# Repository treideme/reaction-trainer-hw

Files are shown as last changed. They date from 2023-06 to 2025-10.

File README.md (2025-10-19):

# Next-Generation Reaction Trainer

This repository contains the hardware design, such as PCB files and
mechanical CAD files for the IoT contest. 

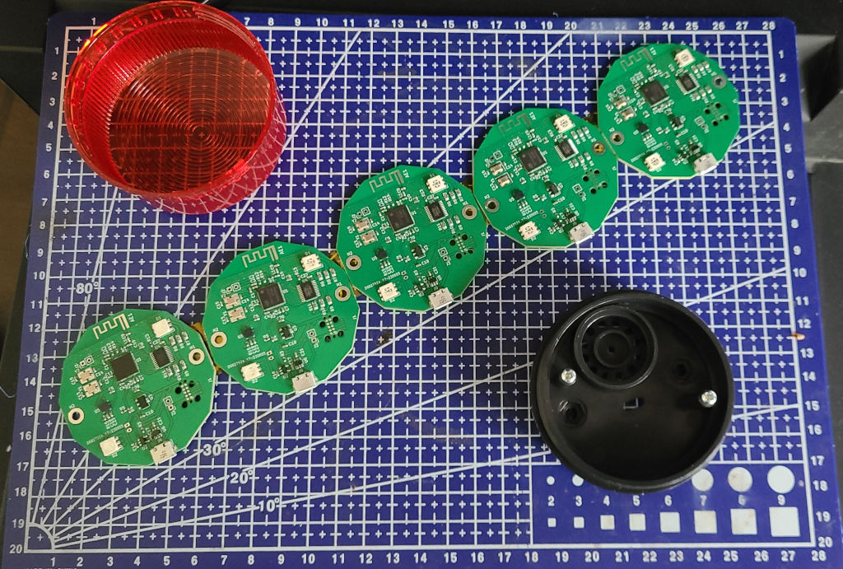
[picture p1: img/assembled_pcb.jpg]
Assembled PCB

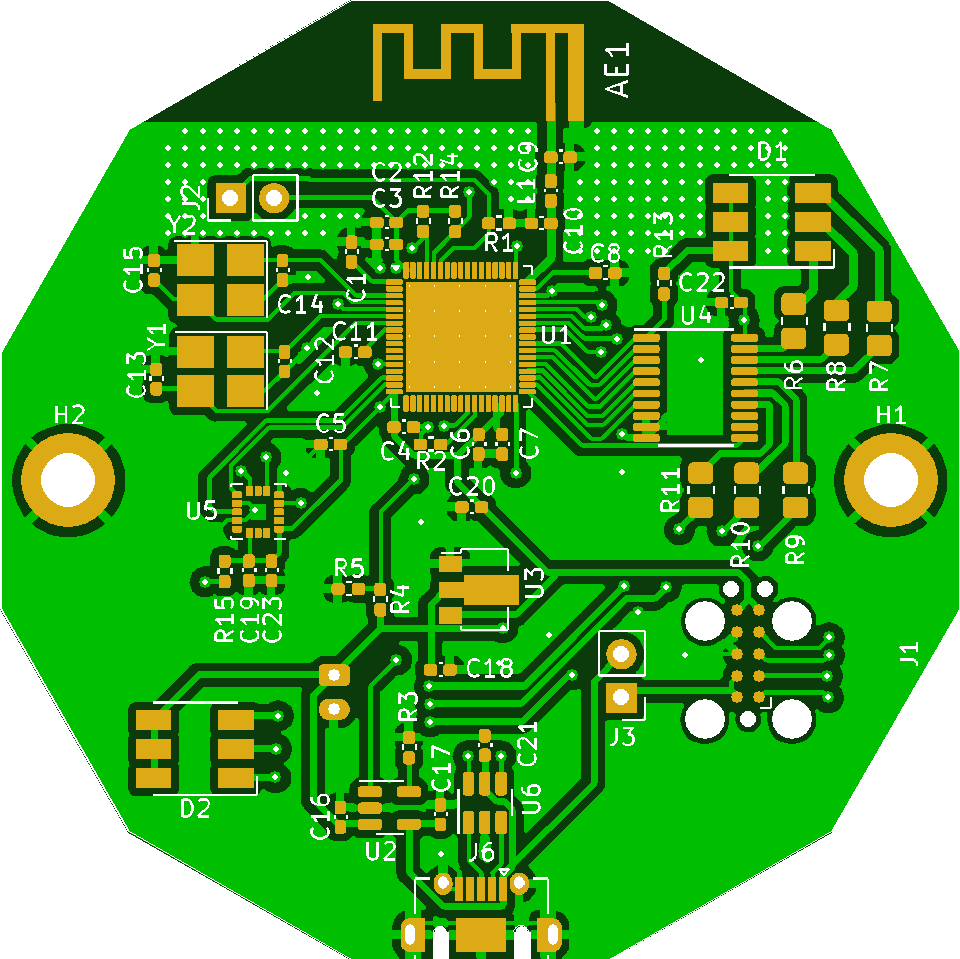
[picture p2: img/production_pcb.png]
Production PCB

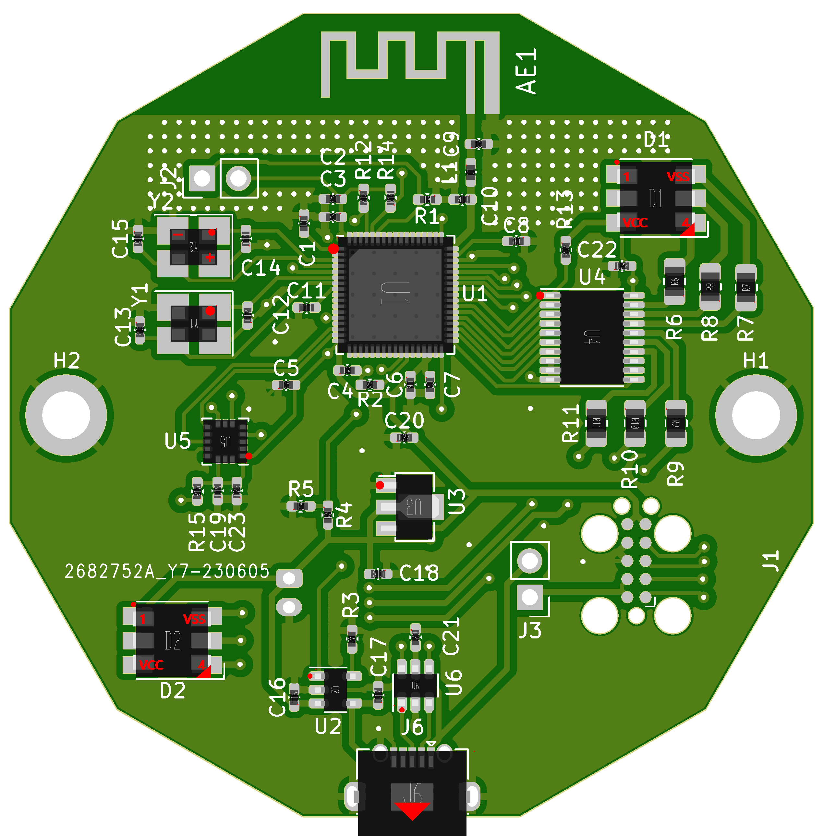
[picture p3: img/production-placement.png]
Production Placement


Please see my [blog post](https://reidemeister.com/blog/2023.06.06)
for a detailed run-down of the design.

## Requirements 
 * Kicad 6+
 * my fork of [WCH Kicad LBR](https://github.com/treideme/wch-kicad-lbr) to get CH32V208W library parts
   * Big shout out to [sad-electronics](https://github.com/sad-electronics) for laying the ground work

See [my blog post](https://www.reidemeister.com/?p=624) for more information and build updates.

 * [Firmware Sources and Overview](https://github.com/treideme/reaction-trainer)
 * [Android Application Sources](https://github.com/treideme/reaction-trainer-app)

## [Bringup](BRINGUP.md)

----
(C) 2023 Thomas Reidemeister, released under [CERN-OHL-P](LICENSE).

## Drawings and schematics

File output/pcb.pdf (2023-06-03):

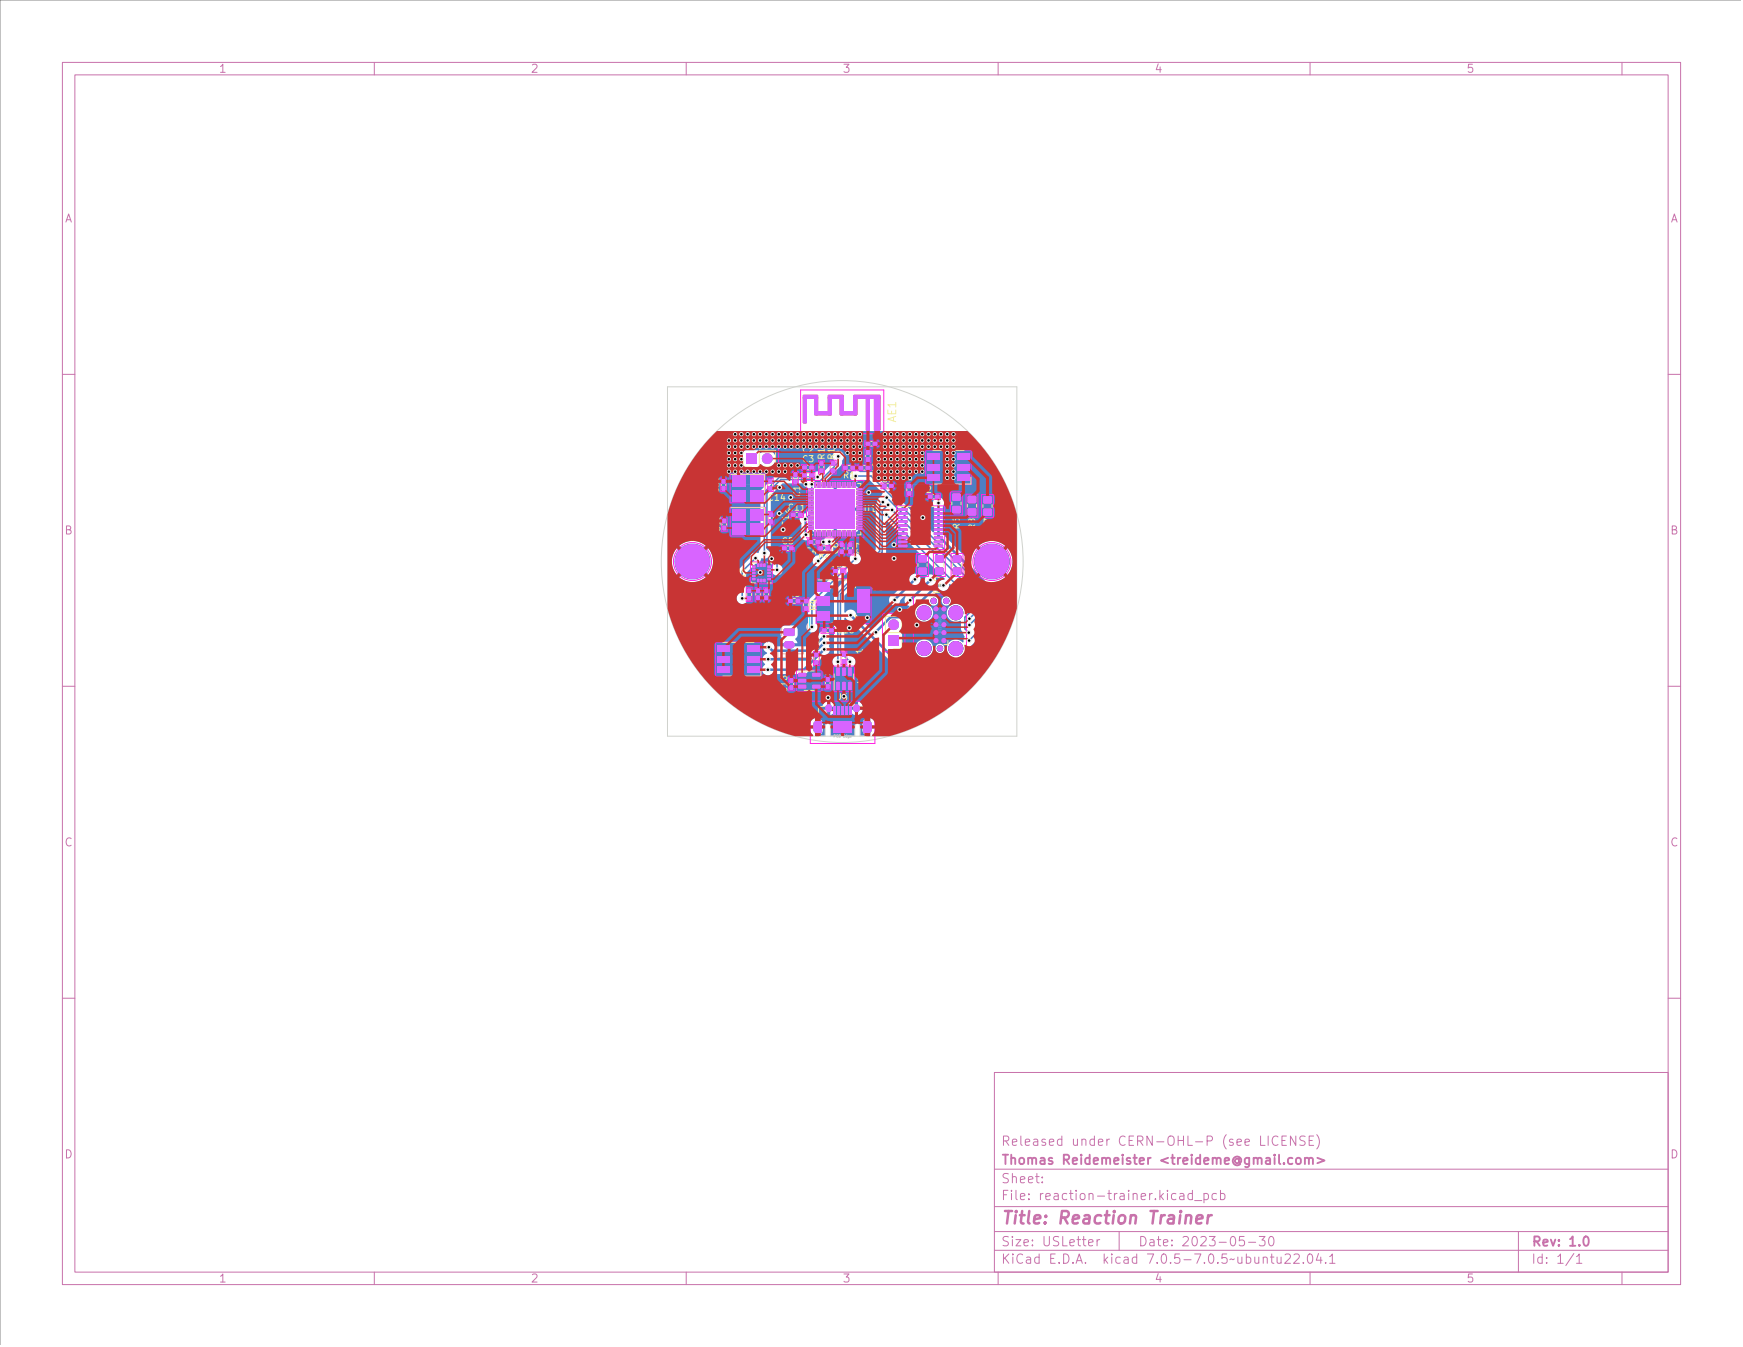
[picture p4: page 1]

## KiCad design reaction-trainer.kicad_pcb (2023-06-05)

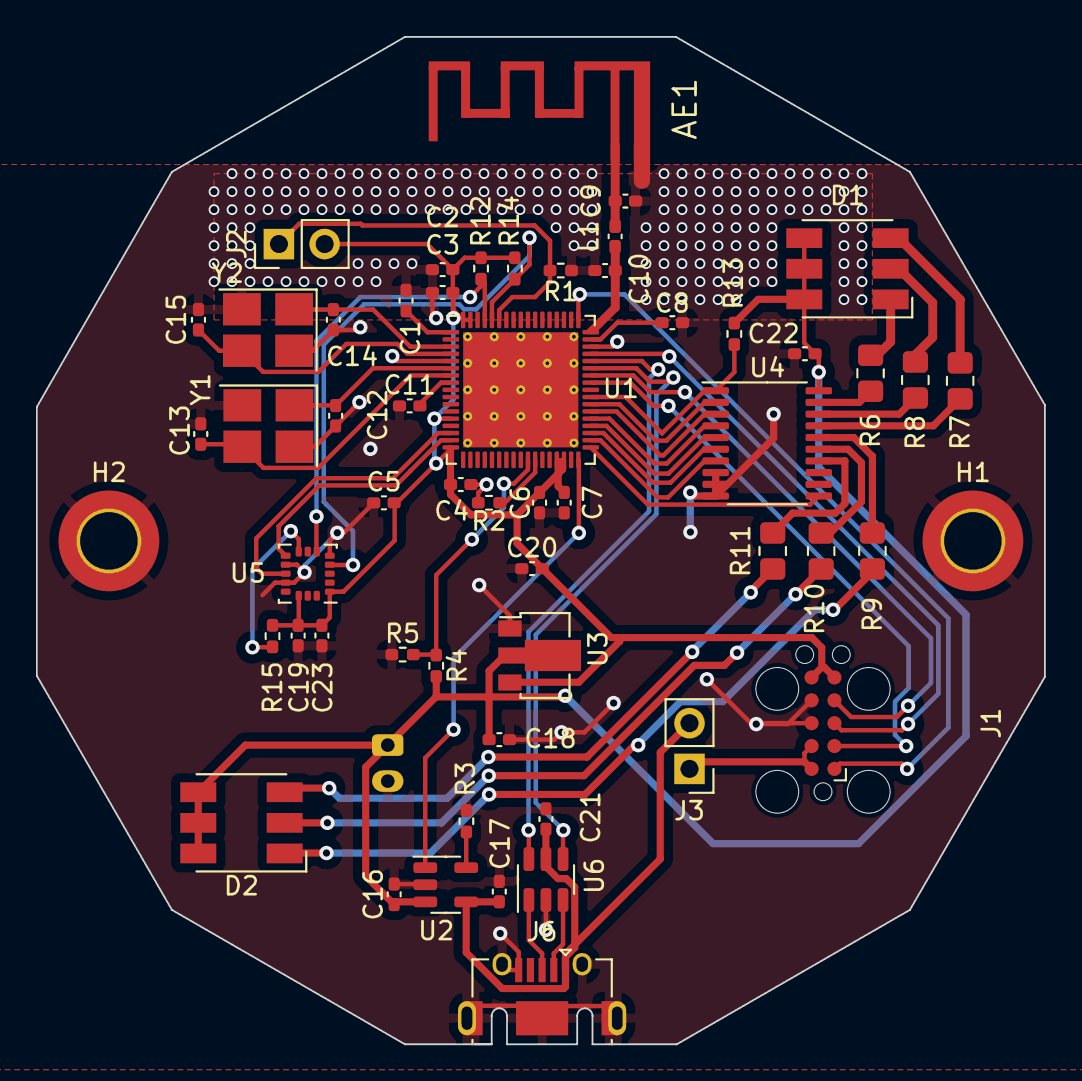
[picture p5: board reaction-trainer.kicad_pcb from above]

Board: 2 copper layers, 56.0 x 56.0 mm, 57 parts (1 on the bottom side), 52 nets.

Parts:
AE1: Antenna_Shield; ANT-F-1-2.4G-1.6MM-FR4-WCH
C1, C2, C3, C4, C5, C6, C7, C11, C21, C22, C23: 0.1uF 20%; C_0402_1005Metric_Pad0.74x0.62mm_HandSolder
C8, C16, C17, C18, C19, C20: 10uF 20%; C_0402_1005Metric_Pad0.74x0.62mm_HandSolder
C9: 1.5pF 5%; C_0402_1005Metric_Pad0.74x0.62mm_HandSolder
C10: 1pF 5%; C_0402_1005Metric_Pad0.74x0.62mm_HandSolder
C12, C13: 12pF 5%; C_0402_1005Metric_Pad0.74x0.62mm_HandSolder
C14, C15: 15pF 5%; C_0402_1005Metric_Pad0.74x0.62mm_HandSolder
D1, D2: C784541; LED_RGB_5050-6
H1, H2: MountingHole_Pad; MountingHole_3.2mm_M3_DIN965_Pad_TopBottom
J1: TC2050; Tag-Connect_TC2050-IDC-FP_2x05_P1.27mm_Vertical
J2, J3: DNP; PinHeader_1x02_P2.54mm_Vertical
J5: JST_PH_B2B; JST_PH_B2B-PH-K_1x02_P2.00mm_Vertical
J6: 47590-0001; USB_Micro-AB_Molex_47590-0001
L1: 1.8nH; L_0402_1005Metric_Pad0.77x0.64mm_HandSolder
R1, R2, R3, R12, R13, R14, R15: 10K 5%; R_0402_1005Metric_Pad0.72x0.64mm_HandSolder
R4: 510K 1%; R_0402_1005Metric_Pad0.72x0.64mm_HandSolder
R5: 1M 1%; R_0402_1005Metric_Pad0.72x0.64mm_HandSolder
R6, R7, R9, R11: 15 5% 125mW; R_0805_2012Metric_Pad1.20x1.40mm_HandSolder
R8, R10: 30 5% 125mW; R_0805_2012Metric_Pad1.20x1.40mm_HandSolder
U1: CH32V208WBU6; QFN-68-1EP_8x8mm_P0.4mm_EP6.4x6.4mm_ThermalVias
U2: MCP73831-2-OT; SOT-23-5
U3: HT7533-1; SOT-89-3
U4: 74HC573PW,118; TSSOP-20_4.4x6.5mm_P0.65mm
U5: LIS3DHTR; LGA-16_3x3mm_P0.5mm_LayoutBorder3x5y
U6: USBLC6-2SC6; SOT-23-6
Y1: 32MHz; Crystal_SMD_3225-4Pin_3.2x2.5mm_HandSoldering
Y2: 32768Hz; Crystal_SMD_3225-4Pin_3.2x2.5mm_HandSoldering

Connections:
+3V3: C2.1, C3.1, C4.1, C5.2, C6.1, C7.1, C19.2, C20.2, C23.2, J1.5, J1.6, J2.2, R12.1, R14.2, R15.2, U1.13 (VDDA), U1.17 (VIO_4), U1.31 (VIO_1), U1.32 (VDD_1), U1.67 (VIO_3), U1.68 (VDD_3), U3.3 (VOUT), U5.1 (VDD_IO), U5.14 (VDD)
+5V: C17.1, C21.2, J3.2, J6.1 (VBUS), U2.4 (VDD), U6.5 (VBUS)
+BATT: C16.1, C18.2, C22.2, D1.4 (BA), D1.5 (GA), D1.6 (RA), D2.4 (BA), D2.5 (GA), D2.6 (RA), J5.1, R4.2, R13.1, U2.3 (VBAT), U3.2 (VIN), U4.20 (VCC)
/CH32V208W/ANT: AE1.1 (A), C9.1, L1.1
/CH32V208W/ANT1: C10.1, L1.2, U1.51 (ANT)
/CH32V208W/BOOT0: J2.1, R1.2, U1.63 (BOOT0)
/CH32V208W/LED_0: U1.41 (PC8/TXP), U4.2 (D0)
/CH32V208W/LED_1: U1.40 (PC7/RXN), U4.3 (D1)
/CH32V208W/LED_2: U1.39 (PC6/RXP), U4.4 (D2)
/CH32V208W/LED_3: U1.38 (PB15), U4.5 (D3)
/CH32V208W/LED_4: U1.37 (PB14), U4.6 (D4)
/CH32V208W/LED_5: U1.36 (PB13), U4.7 (D5)
/CH32V208W/LED_EN: R13.2, U1.42 (PC9/TXN), U4.1 (OE)
/CH32V208W/LED_LATCH: U1.35 (PB12), U4.11 (Load)
/CH32V208W/MOTION_INT1: U1.15 (PA1/ADC1), U5.11 (INT1)
/CH32V208W/MOTION_INT2: U1.16 (PA2/ADC2), U5.9 (INT2)
/CH32V208W/NRST: C11.2, U1.8 (NRST)
/CH32V208W/OSC32_IN: C14.2, U1.3 (PC14/OSC32IN), Y2.1
/CH32V208W/OSC32_OUT: C15.2, U1.4 (PC15/PSC32OUT), Y2.3
/CH32V208W/OSC_IN: C12.2, U1.6 (OSC_IN), Y1.1
/CH32V208W/OSC_OUT: C13.2, U1.7 (OSC_OUT), Y1.3
/CH32V208W/RXD: J1.4, U1.45 (PA10)
/CH32V208W/SCL: R14.1, U1.64 (PB8), U5.4 (SCL/SPC)
/CH32V208W/SDA: R12.2, U1.65 (PB9), U5.6 (SDA/SDI/SDO)
/CH32V208W/STAT: U1.34 (PD6), U2.1 (STAT)
/CH32V208W/SWCK: J1.1, U1.52 (PA14/SWCLK)
/CH32V208W/SWIO: J1.3, U1.48 (PA13/SWDIO)
/CH32V208W/TXD: J1.2, U1.44 (PA9)
/CH32V208W/USBDM: U1.46 (PA11/USB1DM), U6.4 (I/O2)
/CH32V208W/USBDP: U1.47 (PA12/USB1DP), U6.6 (I/O1)
/CH32V208W/VSENSE: R4.1, R5.2, U1.27 (PB1/ADC9)
/USB/DN_IN: J6.2 (D-), U6.3 (I/O2)
/USB/DP_IN: J6.3 (D+), U6.1 (I/O1)
GND: AE1.2 (Shield), C1.1, C2.2, C3.2, C4.2, C5.1, C6.2, C7.2, C8.1, C9.2, C10.2, C11.1, C12.1, C13.1, C14.1, C15.1, C16.2, C17.2, C18.1, C19.1, C20.1, C21.1, C22.1, C23.1, H1.1, H2.1, J1.7, J1.8, J5.2, J6.5 (GND), J6.6 (Shield), R1.1, R2.2, R3.1, R5.1, U1.5 (VSSA), U1.49 (VSS_2), U1.69 (GND), U2.2 (VSS), U3.1 (GND), U4.8 (D6), U4.9 (D7), U4.10 (GND), U5.5 (GND), U5.10 (GND), U5.12 (GND), U6.2 (GND), Y1.2, Y1.4, Y2.2, Y2.4
unnamed: D1.3 (BK), R7.2
unnamed: D1.2 (GK), R8.2
unnamed: D1.1 (RK), R6.2
unnamed: D2.3 (BK), R11.2
unnamed: D2.2 (GK), R10.2
unnamed: D2.1 (RK), R9.2
unnamed: J1.9, J1.10, J3.1
unnamed: R2.1, U1.28 (PB2/BOOT1)
unnamed: C1.2, U1.1 (VBAT)
unnamed: C8.2, U1.50 (VINTA)
unnamed: R3.2, U2.5 (PROG)
unnamed: R6.1, U4.19 (Q0)
unnamed: R8.1, U4.18 (Q1)
unnamed: R7.1, U4.17 (Q2)
unnamed: R9.1, U4.16 (Q3)
unnamed: R10.1, U4.15 (Q4)
unnamed: R11.1, U4.14 (Q5)
unnamed: R15.1, U5.8 (CS)

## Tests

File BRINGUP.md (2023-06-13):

# Bringup
 1. Populate J2 and close it, this will force the board to go into bootloader first
    Do not connect the battery to J5 yet

 2. Start [WCHISP Tool](http://www.wch-ic.com/downloads/WCHISPTool_Setup_exe.html) (Windows only)
    * Connect USB
    * If the device enumerates -> Deprotect the chip
       
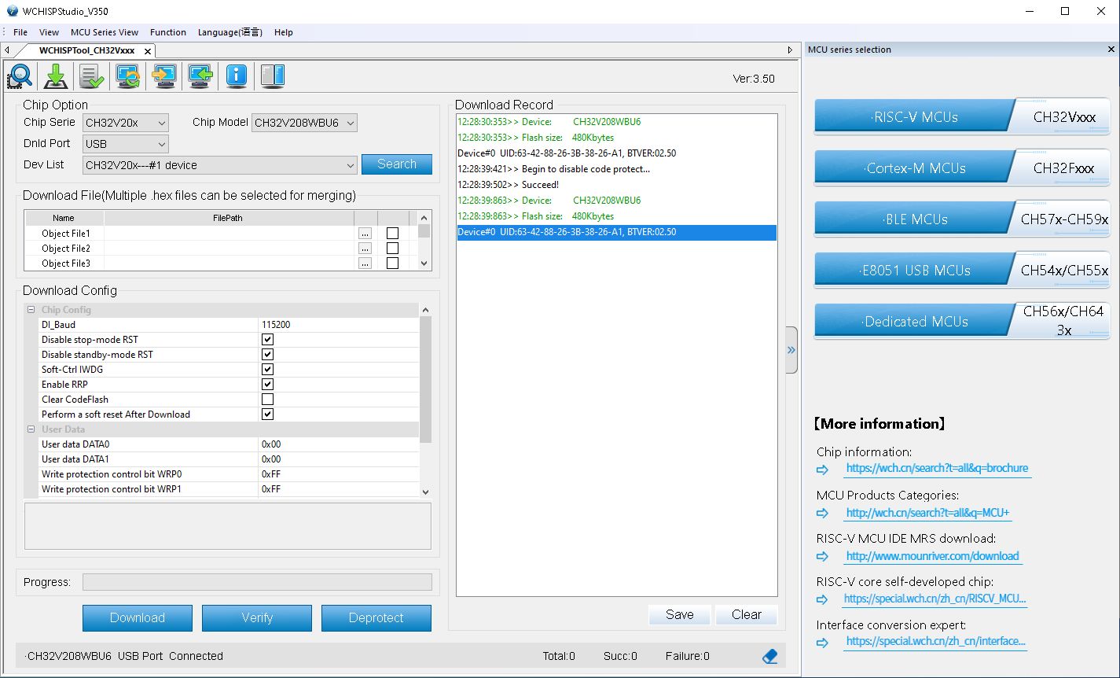
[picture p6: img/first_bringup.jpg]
Deprotecting the Chip
       
    * This confirms that the USB layout is working

 3. Now you can use the WCH-Link to program the device. Note the land pattern for the 
    [Tag-Connect TC2050](https://www.tag-connect.com/product/tc2050-idc-tag-connect-2050-idc) follows the pinout for 
    [WCH-Link-R1-1v1](http://www.wch-ic.com/products/WCH-Link.html), connect the ribbon-adapter such that the red
    ribbon (PIN1) aligns with ```SWCLK```.

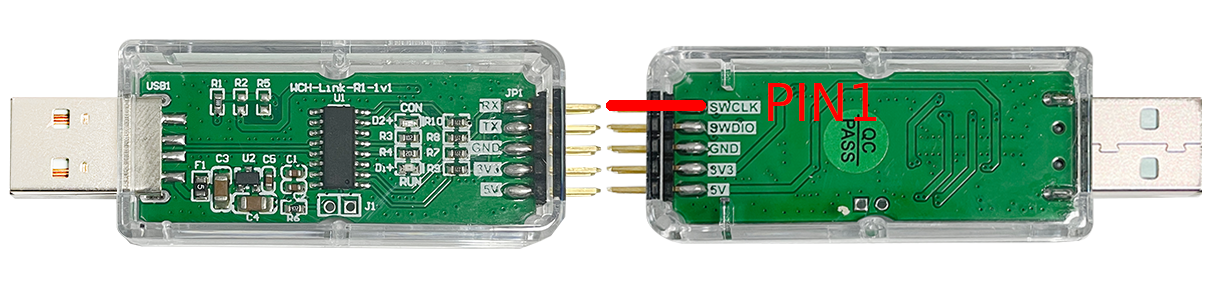
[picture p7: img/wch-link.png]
WCH Link Pin Connection
      

See the [Firmware Repository](https://github.com/treideme/reaction-trainer) for next steps
to set up the device. 

----
Back to [Home](README.md)

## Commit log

2023-05-30 Preliminary framing and library parts
    [reaction-trainer.kicad_pcb, reaction-trainer.kicad_sch]
2023-05-31 Preliminary schematic modules
    [ch32V208w.kicad_sch, led.kicad_sch, motion.kicad_sch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]
2023-05-31 Footprint fix, preliminary pcb
    [led.kicad_sch, reaction-trainer.kicad_pcb]
2023-06-01 Added PWM audio out
    [audio.kicad_sch, reaction-trainer.kicad_sch]
2023-06-01 Added Antenna design
    [audio.kicad_sch, ch32V208w.kicad_sch, reaction-trainer.kicad_pcb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]
2023-06-02 Removed audio, more routing
    [audio.kicad_sch, ch32V208w.kicad_sch, motion.kicad_sch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]
2023-06-03 Added JLPCB DRCs, antenna hatching
    [ch32V208w.kicad_sch, led.kicad_sch, reaction-trainer.kicad_pcb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]
2023-06-05 Field updates, generating fab files
    [ch32V208w.kicad_sch, led.kicad_sch, motion.kicad_sch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]
2023-06-05 Changed outline for DFM
    [ch32V208w.kicad_sch, led.kicad_sch, motion.kicad_sch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]
2023-06-12 Added assembled PCB

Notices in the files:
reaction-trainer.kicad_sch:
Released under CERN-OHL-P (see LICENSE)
